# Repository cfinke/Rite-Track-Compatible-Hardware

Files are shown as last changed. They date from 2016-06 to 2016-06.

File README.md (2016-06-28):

Rite-Track-Compatible Hardware
==============================

3D models of a drawer component socket and case runner guide compatible with the Kenlin Rite-Trak drawer track system.

Printing
========
The case runner can be printed without supports if you printer can manage short overhangs.

The socket is printed in two pieces to avoid requiring support material. After printing, either use acetone to bond the two pieces back-to-back (if using ABS) or superglue for any other material.

Installation
============

Here's a video detailing the installation of the parts:

https://www.youtube.com/watch?v=5WKSNviCPSI

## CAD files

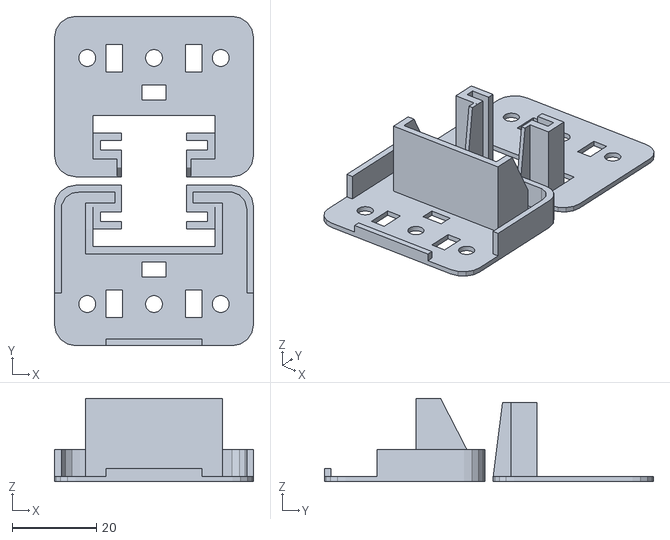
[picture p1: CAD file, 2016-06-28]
Component Socket (Printable).stl
47.3 x 78.3 x 19.7

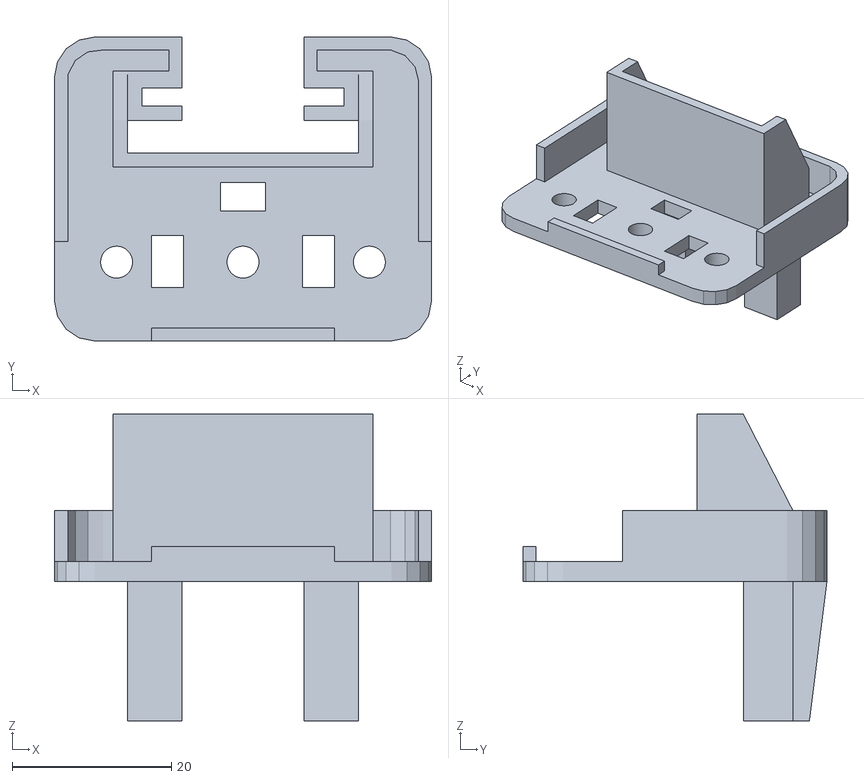
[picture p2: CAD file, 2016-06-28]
Component Socket.stl
47.3 x 38.1 x 38.5

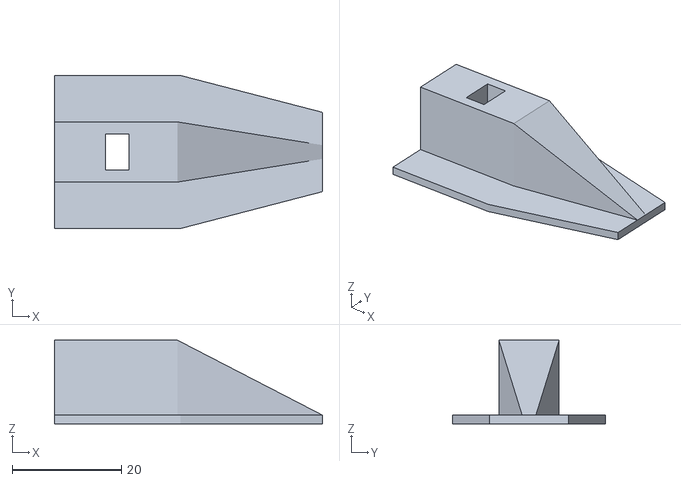
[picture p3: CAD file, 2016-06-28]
Case Runner.stl
49.0 x 28.0 x 15.3

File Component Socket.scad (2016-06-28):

width = 47.3;
height = 38.13;
central_thickness = 2.49;
corner_radius = 5;

module socket() {
    difference() {
        union() {
            linear_extrude(central_thickness) difference() {
                minkowski() {
                    square([width-(2*corner_radius), height-(2*corner_radius)], true);
                    circle(r=5);
                }
            
                translate([0, -(height / 2) + 9.89, 0]) union() {
                    circle(r=2, $fn=100);
                    translate([(width/2) - (4/2) - 5.79, 0, 0]) circle(r=2, $fn=100);
                    translate([-(width/2) + (4/2) + 5.79, 0, 0]) circle(r=2, $fn=100);
                }
            
            
            }
            
            assign(this_height=1.6) {
                translate([0, -(height / 2) + (this_height/2), central_thickness]) cube([22.93, 1.6, 3.75], true);
            }
            
            assign(this_amount_above=6.4, this_total_height=26.4, this_width=28.95, this_top_offset=4.268, this_depth=8.3) {
                translate([0, height/2 - this_depth/2 - this_top_offset, -this_total_height + central_thickness + this_amount_above]) linear_extrude(this_total_height) {
                    square([this_width, this_depth], true);
                }
            }
            assign(this_amount_above=18.5, this_total_height=18.5, this_width=32.61, this_top_offset=10.5, this_depth=5.83) {
                translate([0, height/2 - this_depth/2 - this_top_offset, -this_total_height + central_thickness + this_amount_above]) linear_extrude(this_total_height) {
                    square([this_width, this_depth], true);
                }
            }

            translate([0, 0, central_thickness]) linear_extrude(6.4) difference() {
                minkowski() {
                    square([width-(2*corner_radius), height-(2*corner_radius)], true);
                    circle(r=5);
                }

                assign(this_corner_radius=4) {
                    minkowski() {
                        square([width-(2*this_corner_radius)-(1.6*2), height-(2*this_corner_radius)-(1.6*2)], true);
                        circle(r=this_corner_radius);
                    }
                }

                translate([0, -25.63, 0]) square([width, height], true);
            }

            translate([0, (height/2) - (6.4/2), central_thickness]) linear_extrude(6.4) square([18.55, 6.4], true);

            assign(this_amount_above=6.4, this_total_height=6.4, this_width=32.61, this_top_offset=4.268, this_depth=8.3) {
                translate([0, height/2 - this_depth/2 - this_top_offset, -this_total_height + central_thickness + this_amount_above]) linear_extrude(this_total_height) {
                    square([this_width, this_depth], true);
                }
            }

            assign(this_amount_above=0, this_total_height=18.685+1.31, this_width=17.55, this_top_offset=2.2, this_depth=4.2) {
                translate([0, height/2 - this_depth/2 - this_top_offset, -this_total_height + central_thickness + this_amount_above]) linear_extrude(this_total_height) {
                    square([this_width, this_depth], true);
                }
            }

            translate([-(17.55/2), height/2-2.2, 0]) rotate([-90, 0, -90]) linear_extrude(1.1) polygon(points=[ [0, 0], [0, 17.5], [-2.2, 0] ]);
            mirror([1, 0, 0]) translate([-(17.55/2), height/2-2.2, 0]) rotate([-90, 0, -90]) linear_extrude(1.1) polygon(points=[ [0, 0], [0, 17.5], [-2.2, 0] ]);

            translate([(32.614/2), height/2-10.5, central_thickness + 6.4]) rotate([90, 0, -90]) linear_extrude(1.83) polygon(points=[[0, 0], [0, 12.1], [-6.231, 0]]);

            mirror([1, 0, 0]) translate([(32.614/2), height/2-10.5, central_thickness + 6.4]) rotate([90, 0, -90]) linear_extrude(1.83) polygon(points=[[0, 0], [0, 12.1], [-6.231, 0]]);
        }

        // All of the cut-outs that extend the entire z axis.
        translate([0, 0, -50]) linear_extrude(100) union() {
            translate([0, -(height / 2) + 18.1, 0]) square([5.7, 3.57], true);
        
            assign(this_height=14.5) {
                translate([0, (height / 2) - (this_height/2) + 1, 0]) square([15.35, this_height + 1], true);
            }
        
            assign(this_height=2.27) {
                translate([0, (height / 2) + (this_height/2) - 8.5 - .17, 0]) square([25.35, this_height], true);
            }
        
            assign(this_height=4.1) {
                translate([0, (height / 2) - (this_height/2) - 10.45, 0]) square([28.96, this_height], true);
            }
        
            assign(this_height=6.5) {
                translate([-(width/2) + (4/2) + 12.2, -(height / 2) + (this_height/2) + 6.71, 0]) square([4, this_height], true);
                translate([(width/2) - (4/2) - 12.2, -(height / 2) + (this_height/2) + 6.71, 0]) square([4, this_height], true);
            }
        }
    }
}

module printable_socket() {
    translate( [0, 0, -central_thickness / 2] ) intersection() {
        socket();
        translate([-width / 2, -height / 2, central_thickness / 2]) cube( [ width, height, 999 ] );
    }

    translate([-width, height + 2, 0]) rotate([180, 0, 0]) translate( [width, 0, - central_thickness / 2] ) intersection() {
        socket();
        translate([-width / 2, -height / 2, -999 + (central_thickness / 2)]) cube( [ width, height, 999 ] );
    }
}

socket();
//printable_socket();

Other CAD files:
Case Runner.skp

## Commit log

2014-06-28 Initial import.
    [Case Runner.skp, Case Runner.stl, Component Socket.skp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]
2016-06-28 Reduce complexity of the case runner and remove the need for supports.
    These changes should also make it less likely to crack, and it will fit in the existing hardware without filing or sanding.
    [Case Runner.skp, Case Runner.stl]
2016-06-28 SCAD version of the component socket, along with both the full model STL and printable halves STL.
    [Component Socket (Printable).stl, Component Socket.scad, Component Socket.skp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]
2016-06-28 Updated README to reflect changes to the Component Socket.
